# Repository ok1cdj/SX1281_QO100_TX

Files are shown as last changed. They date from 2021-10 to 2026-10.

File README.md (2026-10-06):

# SX1281_QO100_TX
QO-100 SAT CW and Feld Hell Transmitter with OLED Display using 2.4 GHz LoRa module with TCXO by OM2JU and OK1CDJ

https://www.nicerf.com/products/detail/500mw-2-4ghz-lora-wireless-transceiver-module-lora1280f27-lora1281f27.html

Modes: CW and Feld Hell (122.5 Bd, decoded e.g. by fldigi). Feld Hell is sent as a beacon or as any text from the
[pyCWdclient](pyCWdclient/README.md) client or over HTTP - see [Feld Hell](#feld-hell).

*Maximal power output is 450mW. It is enought to work over satellite with 60cm DISH, but tested also with 35cm and helix feed.*

## Features
- Paddle input -IAMBIC keyer
- Straight key input
- Change frequency, power, keyer speed by rotary encoder
- Frequency callibration
- CW beacon mode
- cwdaemon compatible UDP server on port 6789
- WiFi client or AP mode
- Web interface for WiFi config
- Web interafce for tuning, change speed and power
- New: PTT output on ESP32 module pin-12. This is logic signal, one must add external NPN/MOSFET. Configurable delay.
- Wi-Fi keep-alive: modem sleep off, automatic reconnect (fixes drop-outs with mesh APs such as TP-Link Deco)
- Firmware and web files update over Wi-Fi (OTA) - see below
- Feld Hell: beacon set from the web page, text sent from the client or over HTTP - see below
- Python client [pyCWdclient](pyCWdclient/README.md) for desktop and iPad: CW and Feld Hell TX, Feld Hell RX,
  frequency and power control, QSO logging to Wavelog
- Web interface usable on mobile phones

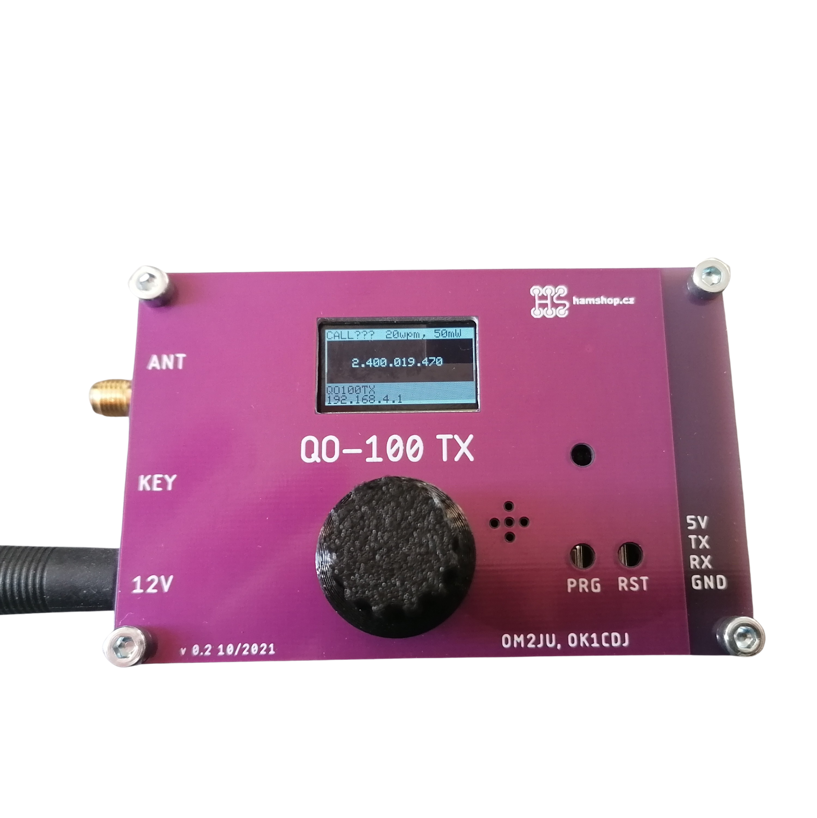
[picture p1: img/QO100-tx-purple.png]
QO-100 TX


## Python client (pyCWdclient)
[`pyCWdclient/`](pyCWdclient/README.md) is a desktop (Tk) and iPad (Pythonista) client for the keyer:
CW macros over UDP (cwdaemon protocol), Feld Hell TX through the web API, Feld Hell receiver
(Linux, audio from an SDR), TX frequency and power control, frequency memories and QSO logging
to Wavelog.

```sh
cd pyCWdclient
cp config.example.json config.json   # keyer IP, call, Wavelog
python3 pyCWdclient.py
```

## Used libraries
Adafruit GFX Library

Adafruit_SSD1306

SX12XX Library - https://github.com/StuartsProjects/SX12XX-LoRa

ESPAsyncWebServer - https://github.com/me-no-dev/ESPAsyncWebServer

AsyncTCP - https://github.com/me-no-dev/AsyncTCP

## Building with PlatformIO
`platformio.ini` builds with Arduino-ESP32 core 2.0.17 (core 3.x is not supported). The web
interface lives in `data/` and goes to the SPIFFS partition.

```sh
pio run -t upload        # firmware over USB
pio run -t uploadfs      # web files over USB
```

## OTA update
Open `http://<keyer IP>/update?apikey=<APIKEY>`, choose *Firmware* (`firmware.bin`) or
*Web files* (`spiffs.bin`) and press Update. The keyer restarts after a successful upload;
settings are kept. With PlatformIO:

```sh
KEYER_APIKEY=1111 pio run -e ota -t upload   --upload-port <keyer IP>
KEYER_APIKEY=1111 pio run -e ota -t uploadfs --upload-port <keyer IP>
```

There is no automatic rollback - a firmware that does not start needs a USB flash
(hold BOOT, press EN).

## Feld Hell
Standard Feld Hell (7x14 font, 245 pixels/s, 2.5 characters/s, on/off keying), decoded by the
Feld Hell mode of fldigi. Text, number of repetitions (0 = until Stop) and pause between them
are set on the web page and kept after restart; `%CALL%` in the text is replaced by MyCall.
Start/Stop from the web page, from the menu (*Beacon FHELL*) or by HTTP:

```sh
curl "http://<keyer IP>/hell?apikey=<APIKEY>&cmd=start"   # cmd=stop, no cmd = status
```

Any text can be sent once with `cmd=send&txt=<text>`; text sent while the keyer is still
transmitting is appended (up to 512 characters). This is what the pyCWdclient client uses in its
Hell mode (macros and free text); the client also receives Feld Hell from an SDR.

Break (web, UDP) or the encoder push button stops Feld Hell and drops the rest of the text.
CW text is not sent while Feld Hell is being transmitted.

## User interface
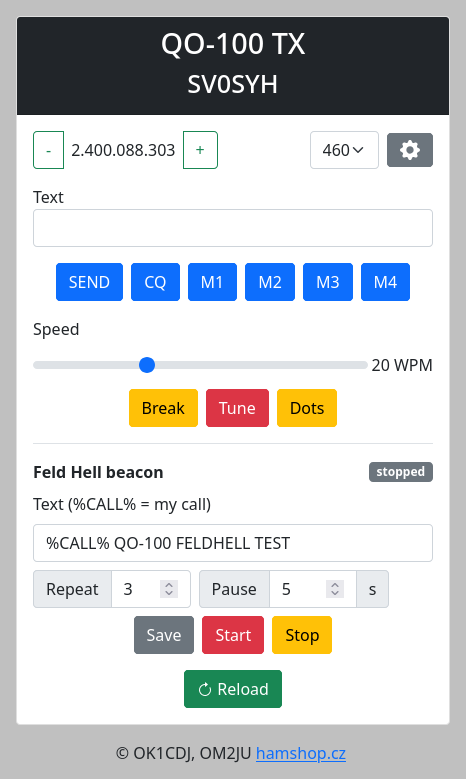
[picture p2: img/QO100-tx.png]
Web interface


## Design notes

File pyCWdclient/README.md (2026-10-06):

# pyCWdclient

Tk GUI client for [cwdaemon](https://github.com/acerion/cwdaemon) compatible keyers (e.g. an ESP32 keyer)
for CW and Feld Hell operation via QO-100. Sends CW macros over UDP and logs QSOs to [Wavelog](https://github.com/wavelog/wavelog) as ADIF.

Part of [SX1281_QO100_TX](https://github.com/ok1cdj/SX1281_QO100_TX) - the client for its keyer
(CW and Feld Hell TX, Feld Hell RX, frequency and power control).

## Setup

```sh
pip install -r requirements.txt
cp config.example.json config.json   # edit IP, station, macros, Wavelog
python pyCWdclient.py
```

QSOs are uploaded to [Wavelog](https://github.com/wavelog/wavelog) (`wavelog` in the config: URL,
API key with write rights, station profile ID). Cloudlog works too; an old `cloudlog` config key
is still read.

Wavelog credentials can also be given on the command line (they override the config):

```sh
python pyCWdclient.py <url> <api_key> <station_id>
```

## Macros

Placeholders: `{mycall}`, `{name}`, `{myloc}` (from `station`), `{call}`, `{rst}` (from the GUI).

## Keys

| Key | Action |
|-----|---|
| F1 | CQ |
| F2 | Report (`rpt` macro) |
| F3 | TU 73 |
| F4 | de .. |
| F5 / Enter | Send free text |
| Esc | Stop transmission (CW abort + keyer Break) |
| F6 | Dots (keyer) |
| PgUp / PgDn | Tune up / down by the selected step |

## Pythonista (iPad / iPhone)

`pyCWdclient_ios.py` is the same client with a touch UI for [Pythonista 3](http://omz-software.com/pythonista/).
The logic (cwdaemon, keyer, tuning, memories, ADIF, Wavelog) is shared in `cwcore.py`;
`pyCWdclient.py` is the Tk frontend.

1. Copy `cwcore.py`, `pyCWdclient_ios.py` and your `config.json` into one Pythonista folder
   (e.g. via iCloud Drive / the Files app). No extra packages are needed.
2. Run `pyCWdclient_ios.py`. Allow *Local Network* access for Pythonista when iOS asks
   (Settings → Pythonista → Local Network), otherwise UDP and the keyer are unreachable.
3. Memories are stored in `memories.json` next to the config, separately from the desktop.

Memories: *Save* stores the current frequency, *Memories* lists them — tap to tune, swipe left
to delete. With a hardware keyboard: Esc = STOP, ⌘1–⌘4 = CQ / Report / TU 73 / de ..,
⌘D = Dots, ⌘↑ / ⌘↓ = tune, ⌘L = Log QSO.

`../UDP_Test_script.py` is a standalone UDP test script (sends a test message at 15 and 30 WPM).

## Frequency

If `keyer_web.url` is set, the TX frequency is read from the QO-100 TX keyer web page
(`frq_index × STEP`, polled every `poll_s` seconds), shown in the app and logged with each QSO.
`FREQ_RX` is TX + `adif.rx_offset_mhz` (8089.5 MHz for the QO-100 NB transponder).
If the keyer is unreachable, `adif.freq` is logged.

Tuning: `−`/`+` buttons, mouse wheel over the frequency or PgUp/PgDn, with a selectable step
(one keyer step ≈ 198 Hz, 1/10/100 kHz; kHz steps snap to the grid). Type a frequency in MHz
and press GO/Enter to jump to it. Memories are saved to `memories.json` next to the config.

`keyer_web.correction_hz` corrects the TCXO offset: set it to
*real frequency (SDR/GPS) − frequency shown with correction 0*.

## Dots and power

`DOTS` (F6) makes the keyer send a series of dots (25× E) for tuning onto the transponder.
STOP / Esc aborts CW and sends Break, which clears the keyer's CW queue.
Power is selected from the levels offered by the keyer and follows changes made in its web UI.

## Feld Hell

The CW / Hell switch (F7, ⌘H on the iPad) sends macros and free text in Feld Hell instead of
CW. Hell text goes to the keyer over its web API (`/hell?cmd=send`, needs `keyer_web` and
keyer firmware v1.7+); messages sent while the keyer is still transmitting are appended.
STOP sends Break, which also stops Hell. QSOs logged in Hell mode get `MODE=HELL`.

### Receiving (Tk on Linux)

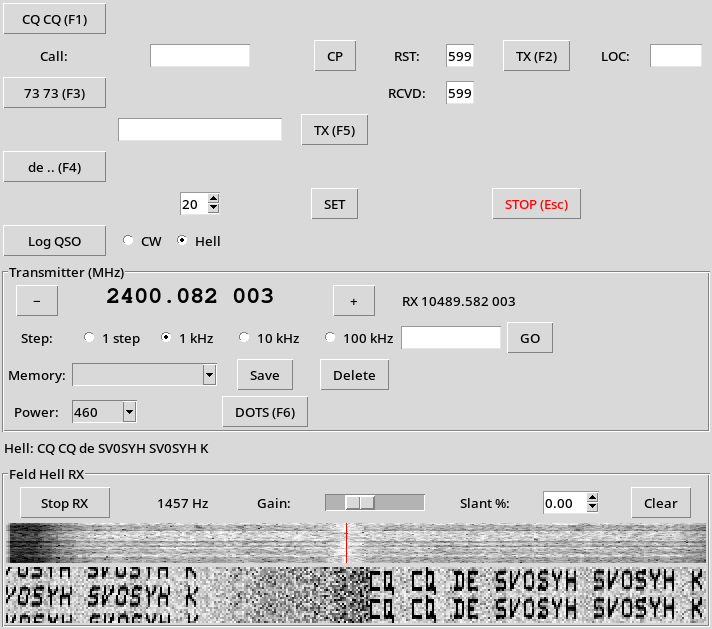
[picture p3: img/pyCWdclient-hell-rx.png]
pyCWdclient receiving Feld Hell


The *Feld Hell RX* panel decodes Feld Hell from audio, e.g. a WebSDR playing in the
browser. It needs `numpy` and `parec` (PulseAudio / PipeWire); without them the panel is
hidden. Audio is taken from `hell_rx.source`, by default `@DEFAULT_MONITOR@` = whatever plays
in the default output. A different source can be chosen in `pavucontrol` → Recording.

Start RX, click the signal in the waterfall (0–3 kHz) to set the tone, adjust Gain for
contrast and Slant % if the text leans. Each column is drawn twice on top of each other, as in
fldigi, so a full character is always readable in one of the copies.

`python3 hellrx.py ../Settings.h out.pgm "TEXT"` decodes a generated
test signal offline (font read from the keyer firmware).

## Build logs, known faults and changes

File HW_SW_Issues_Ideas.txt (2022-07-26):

--------------------------------------------------------
JU - comments to initial PCB revision from 24.08.2021:
  
  - move LD117ADT more to left or right so that we can put there distance pole for OLED display (right hole is OK, left one intersects with LD117ADT)
    Note: with max. output power the current drawn is very high and will not work with standard USB port. Solution is to set lower output power.
--------------------------------------------------------
JU 2022-07-26: 
I have soldered micro-USB receptacle so that the SX1281_QO100_TX can be supplied by USB power bank.
From micro-USB receptacle simply connect:
- the 5V pin  (pin-1 = VBUS) to 5V rail on SX1281_QO100_TX
- the GND pin (pin-5 = GND) to GND on SX1281_QO100_TX
--------------------------------------------------------

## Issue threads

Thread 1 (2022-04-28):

Wrong Buzzer initialisation ...

F5MDY, 2022-04-28:
Good job !!

In the setup () wrong Buzzer Channel initialization

Original :

 // Configure BUZZER functionalities.
  ledcSetup(3, 8000, 8);   //PWM Channel, Freq, Resolution
  /// Attach BUZZER pin.
  ledcAttachPin(BUZZER, 3);  // Pin, Channel

should become :

 // Configure BUZZER functionalities.
  ledcSetup(9, 8000, 8);   //PWM Channel, Freq, Resolution
  /// Attach BUZZER pin.
  ledcAttachPin(BUZZER, 9);  // Pin, Channel

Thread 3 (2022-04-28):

No power output modification

F5MDY, 2022-04-28:
I use a E282G4M27S from Ebyte (without TCXO ... it's a pitty) and the output power is always the same (22dBm) regardless the output power selection.
73

renef6bir, 2022-05-24:
Bonjour avez vous finalisé le projet, j'en suis à la réalisation d'une maquette et il me manque quelques infos
Jutilise un NodeMcu-esp32s et un  LoRa1281f27 sans TCXO
73 René F6bir

renef6bir, 2022-06-07:
Je bloque sur la ligne 1322
**_if (LT.begin(NSS, NRESET, RFBUSY, DIO1, DIO2, DIO3, RX_EN, TX_EN, SW, LORA_DEVICE))_**
Pas de réponse du module ? le serial print monitor  indique la date la version et "SPI OK"
Le display Oled se termine par "Starting WiFi..."
L'essai du module LoRa avec un Arduino nano et plusieurs exemples de la Lib est concluant je vois l'émission 2.4G en DSB avec ou sans l'ampli inboard ( TXEN ou non)

Je souhaitais procéder par étapes et je n'ai pas encore câblé l'encodeur....
Je ne me suis  pas encore soucié du WiFi....
J'ai testé toutes variations du Settings.h qui concerne le module LoRa1281, j'ai vérifié plusieurs fois le câblage.
J'ai tenu compte des différences de pinout entre l'ESP-WROOM-32 et le NodeMCU-esp32s que j'utilise, mais est ce bien compatible ? (voir pdf joint)
La LED1 (IO2) (IO15 dans le settings) ne réagit pas dans aucun des " **_examples_** " de test avec Arduino Nano ou Uno.

Pour info , par ailleurs, j'ai une balise WSPR , à base de raspi, opérationnelle H24 sur QO100 freq  10489.569500 MHz : fréquence du signal, pwr (+17dBm) parabole offset de 60cm hélice 5tr,  upconverter DXPatrol seul, les OL sont GPS locked,  reçu -17dBm sur les WebSDR QO100
Pour la puissance de sortie du LoRa l'alimenter en 3.3v au lieu de 5v (si ce n'est déja fait ) TXEN ne mettrait en service que le PA du module, si j'ai bien cerné le produit.
Auriez vous le schéma de votre réalisation, je n'ai que celui disponible sur GitHub.
Merci pour le retour  73 René f6bir@sfr.fr

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

F5MDY, 2022-06-08:
I found my error ..... I use a SX1280 module (E28-2G4M27S) which have a 27dB PA.
If you check the SX128XLT library, the function setTxParams(int8_t TXpower, uint8_t RampTime) add 18 to the TXpower value (which is given in dBm for SX1280 standalone). So the PowerArrayMiliWatt table values in the program are to high for my module, and its saturate. This is the new correct table for this module :

#define PowerArrayMiliWatt_Size 7
//
// { Power_mW, Reg-setting }
const uint32_t PowerArrayMiliWatt [][2] = {
  {  0,  0 },   // 0mW = no output power, special case
  { 15,  -13 },   // cca 15 mW
  { 25,  -10 },   // cca 25 mW
  { 50, -7 },   // cca 50 mW
  { 100, -4},   // cca 100 mW
  { 150, -2 },  // cca 150 mW
  { 220, 1 }   // cca 220 mW
};

Best 73, Nico

F5MDY, 2022-06-08:
TO René :

J'ai vraiment le minimum pour la connection au module :

#define NSS 5                                  //select pin on LoRa device
#define SCK 18                                  //SCK on SPI3
#define MISO 19                                 //MISO on SPI3
#define MOSI 23                                 //MOSI on SPI3

#define NRESET 32                               //reset pin on LoRa device
#define RFBUSY 33                               //busy line

#define LED1 -1                                 //on board LED, high for on
#define DIO1 26                                 //DIO1 pin on LoRa device, used for RX and TX done
#define DIO2 -1                                 //DIO2 pin on LoRa device, normally not used so set to -1
#define DIO3 -1                                 //DIO3 pin on LoRa device, normally not used so set to -1
#define RX_EN -1                                //pin for RX enable, used on some SX128X devices, set to -1 if not used
#define TX_EN -1                                 //pin for TX enable, used on some SX128X devices, set to -1 if not used
#define BUZZER 12                               //pin for buzzer, set to -1 if not used
#define VCCPOWER -1    //JU-not needed by module          //pin controls power to external devices
#define LORA_DEVICE DEVICE_SX1281               //we need to define the device we are using
#define TCXO_EN -1

J'ai été un peu feignant pour l'implantation : j'ai utilisé des PCB que j'avais d'un autre projet :
https://github.com/thingsat/tinygs_2g4station#buy en apportant quelques modifs.
Mais pour le module 2.4G il est connecté comme décrit

Attention je n'ai pas de SW sur ma ligne 1322 :
  if (LT.begin(NSS, NRESET, RFBUSY, DIO1, DIO2, DIO3, RX_EN, TX_EN, LORA_DEVICE))  {

J'irai écouter votre balise merci de l'info.

73
Nico

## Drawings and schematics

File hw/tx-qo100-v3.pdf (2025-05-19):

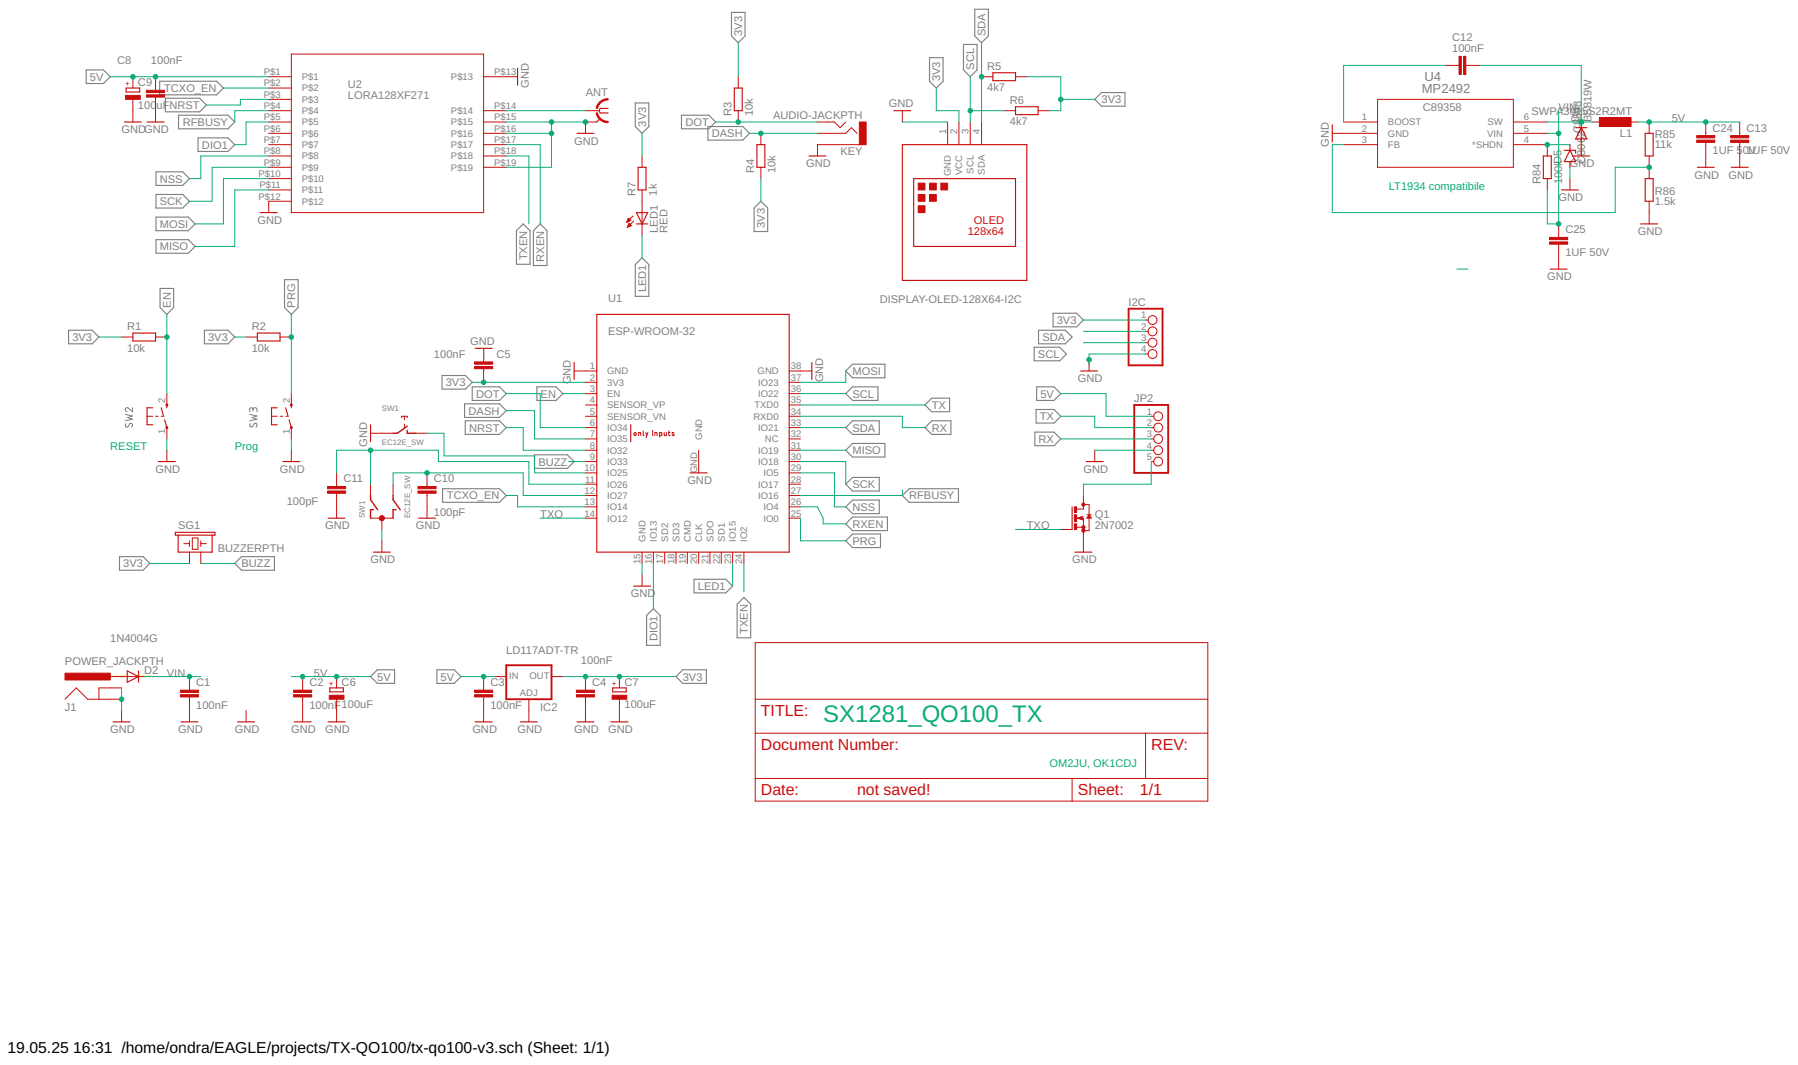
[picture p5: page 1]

Document Number: OM2JU, OK1CDJ | REV:

Date: not saved! | Sheet: 1/1

19.05.25 16:31 /home/ondra/EAGLE/projects/TX-QO100/tx-qo100-v3.sch (Sheet: 1/1)

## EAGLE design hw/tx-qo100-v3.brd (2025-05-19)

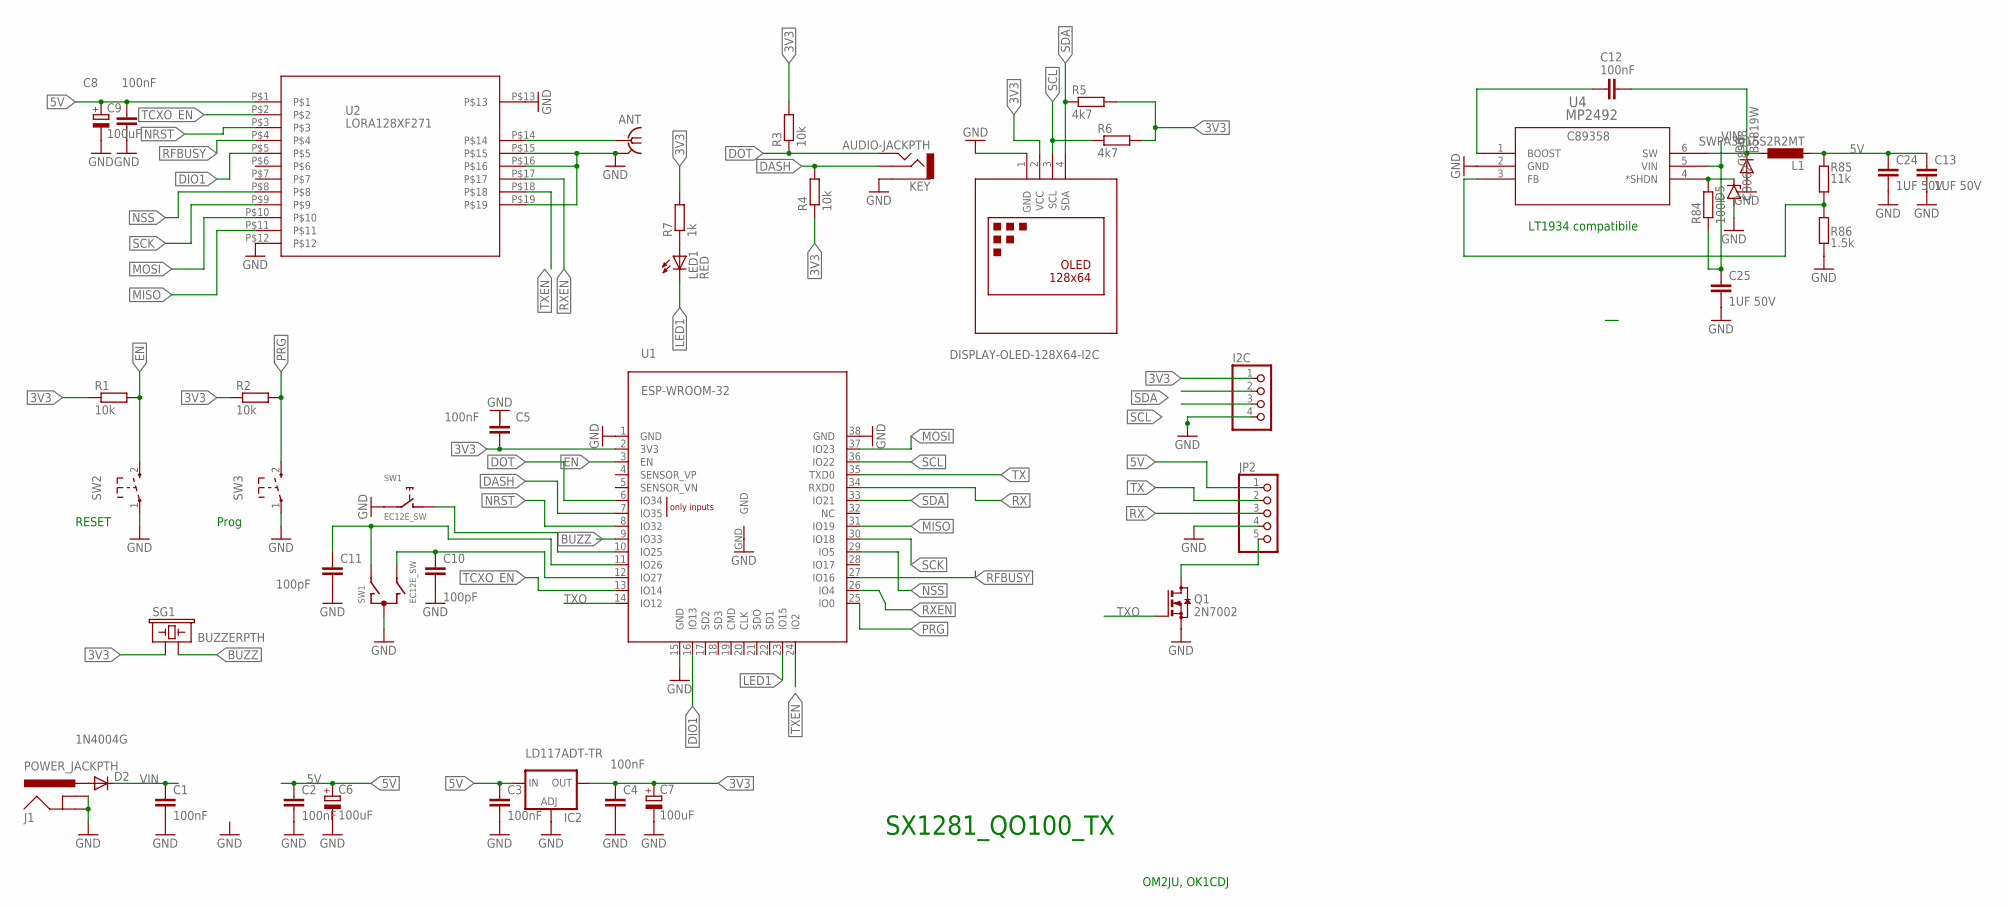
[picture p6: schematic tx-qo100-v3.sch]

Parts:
ANT: SMA-142-0711-821/826; J502-ND-142-0711-821/826
C1, C2, C3, C4, C5, C8, C12: 100nF; C0603
C6, C7, C9: 100uF; SMC_B; LCSC_PART C16133
C10, C11: 100pF; C0603
C13, C24, C25: 1UF 50V; C0603; LCSC_PART C15849
D2: 1N4004G; DO-214AC; LCSC_PART C433394
D5: C8062; SOD80C; LCSC_PART C8062
D6: B5819W; SOD123; LCSC_PART C8598
I2C: PINHD-1X4; 1X04
IC2: LD117ADT-TR; DPACK; LCSC_PART C358375
J1: POWER_JACKPTH; POWER_JACK_PTH
JP2: PINHD-1X5/90; 1X05/90
KEY: AUDIO-JACKPTH; AUDIO-JACK
L1: SWPA3015S2R2MT; L2825P; LCSC_PART C43389
LED1: RED; CHIP-LED0805; LCSC_PART C84256
Q1: 2N7002; SOT23; LCSC_PART C8545
R1, R2, R3, R4: 10k; R0603
R5, R6: 4k7; R0603
R7: 1k; R0603
R84: 100k; R0603
R85: 11k; R0603
R86: 1.5k; R0603
SG1: BUZZERPTH; BUZZER-12MM; LCSC_PART C360607
SW1: EC12E_SW; ALPS_EC12E_SW
SW2, SW3: SW_TACT_2P-3X6; SW_TACT_3X6; LCSC_PART C520860
U1: ESP-WROOM-32
U2: LORA128XF271; LORA128XF27
U4: MP2492; SOT-6_S; LCSC_PART C89358
U$1: DISPLAY-OLED-128X64-I2C

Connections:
3V3: C4.1, C5.1, C7.+, I2C.1, IC2.4 (OUT), R1.1, R2.1, R3.2, R4.1, R5.2, R6.2, R7.2, SG1.+ (1), U1.2 (3V3), U$1.2 (VCC)
5V: C2.1, C3.1, C6.+, C8.1, C9.+, C13.1, C24.1, IC2.3 (IN), JP2.1, L1.2, R85.1, U2.P$1
BST: C12.2, U4.1 (BOOST)
BUZZ: SG1.- (2), U1.9 (IO33)
DASH: KEY.2, R4.2, U1.7 (IO35)
DIO1: U1.16 (IO13), U2.P$5
DOT: KEY.5, R3.1, U1.6 (IO34)
EN: R1.2, SW2.2 (3), U1.3 (EN)
GND: ANT.G@1 (2), ANT.G@2 (2), ANT.G@3 (2), ANT.G@4 (2), C1.2, C2.2, C3.2, C4.2, C5.2, C6.-, C7.-, C8.2, C9.-, C10.2, C11.2, C13.2, C24.2, C25.2, D5.A, D6.A, I2C.4, IC2.1 (ADJ), J1.GND, J1.GNDBREAK, JP2.4, KEY.1, Q1.2 (S), R86.1, SW1.C, SW1.E (2), SW2.1, SW3.1, U1.1 (GND), U1.15 (GND), U1.38 (GND), U1.GND, U2.P$12, U2.P$13, U2.P$15, U2.P$16, U2.P$19, U4.2 (GND), U$1.1 (GND)
IN: D2.A, J1.PWR
LED1: LED1.C, U1.23 (IO15)
MISO: U1.31 (IO19), U2.P$11
MOSI: U1.37 (IO23), U2.P$10
unnamed: ANT.1, U2.P$14
unnamed: C10.1, SW1.B, U1.12 (IO27)
unnamed: LED1.A, R7.1
unnamed: C11.1, SW1.A, U1.11 (IO26)
unnamed: SW1.D (1), U1.10 (IO25)
unnamed: JP2.5, Q1.3 (D)
unnamed: D5.C, R84.2, U4.4 (*SHDN)
unnamed: R85.2, R86.2, U4.3 (FB)
NRST: U1.8 (IO32), U2.P$3
NSS: U1.29 (IO5), U2.P$8
PRG: R2.2, SW3.2 (3), U1.25 (IO0)
RFBUSY: U1.27 (IO16), U2.P$4
RX: JP2.3, U1.34 (RXD0)
RXEN: U1.26 (IO4), U2.P$17
SCK: U1.30 (IO18), U2.P$9
SCL: I2C.3, R6.1, U1.36 (IO22), U$1.3 (SCL)
SDA: I2C.2, R5.1, U1.33 (IO21), U$1.4 (SDA)
SW: C12.1, D6.C, L1.1, U4.6 (SW)
TCXO_EN: U1.13 (IO14), U2.P$2
TX: JP2.2, U1.35 (TXD0)
TXEN: U1.24 (IO2), U2.P$18
TXO: Q1.1 (G), U1.14 (IO12)
VIN: C1.1, C25.1, D2.C, R84.1, U4.5 (VIN)

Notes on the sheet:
RESET
Prog
SX1281_QO100_TX
OM2JU, OK1CDJ
LT1934 compatibile

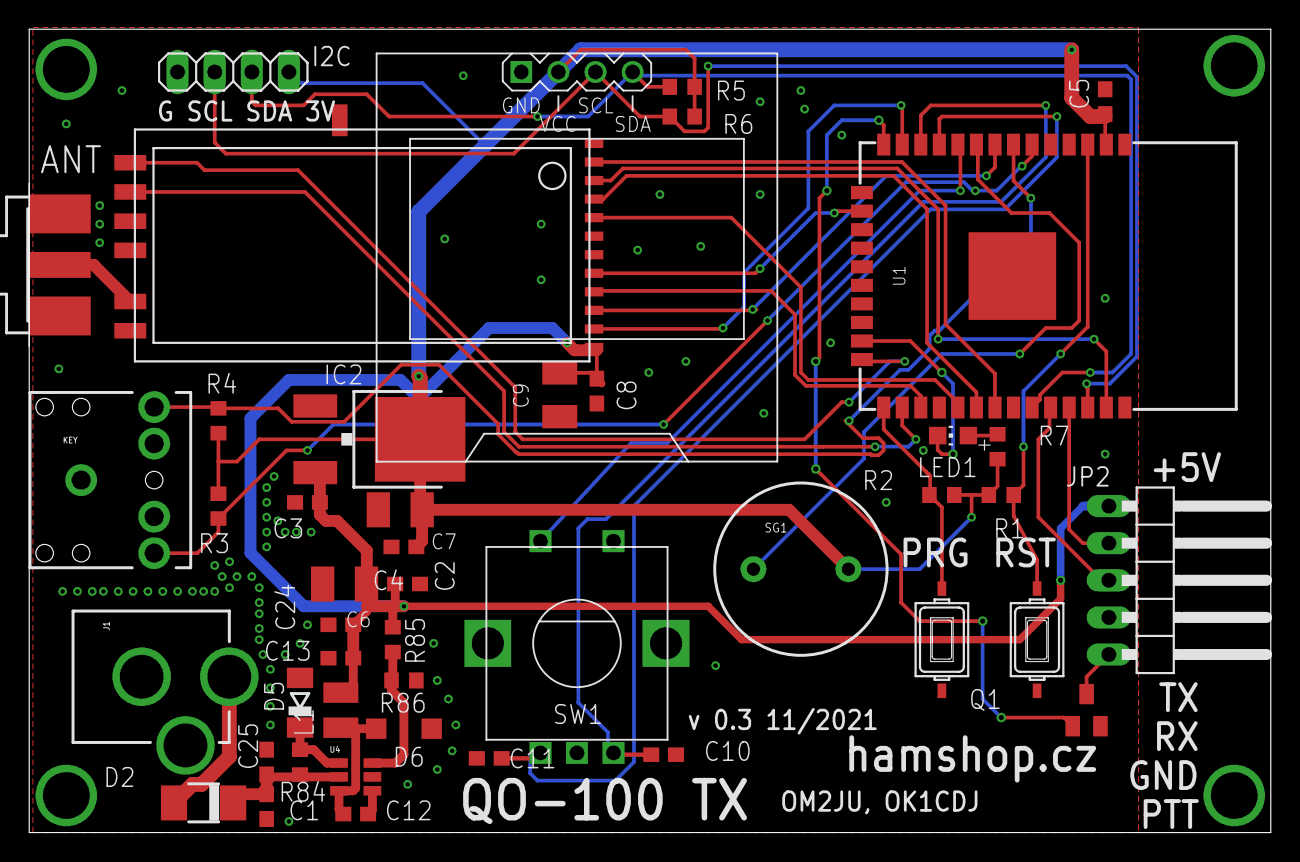
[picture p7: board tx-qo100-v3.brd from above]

Board: 2 copper layers, 85.0 x 55.0 mm, 45 parts (0 on the bottom side), 36 nets.

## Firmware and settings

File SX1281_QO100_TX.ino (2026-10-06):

//
// 2021-08  QO-100 SAT CW Transmitter with OLED Display
// by Jan Uhrin, OM2JU and Ondrej Kolonicny, OK1CDJ
//
//
//
// Power level settings - from documentation of LoRa128xF27 module
// LEV dBm  mA    Reg value
// 9  26.4  520   13
// 8  25.5  426   10
// 7  23.4  343   7
// 6  20.85 268   4
// 5  18.26 229   1
// 4  15.2  182   -2
// 3  12.3  155   -5
// 2  9.3   138   -8
// 1  6.0   130   -12
// 0  3.0   125   -15
//
// SX128x datasheet:  Pout (dB) = -18 + Reg_Value
//
//

#include <Adafruit_GFX.h>
#include <Adafruit_SSD1306.h>
#include <Preferences.h>

#include <WiFi.h>
#include <ESPAsyncWebServer.h>
#include <AsyncUDP.h>
#include <SPIFFS.h>
#include <Update.h>


#include "time.h"
#include <SPI.h>                                               //the lora device is SPI based so load the SPI library                                         
#include <SX128XLT.h>                                          //include the appropriate library  
#include "Settings.h"                                          //include the setiings file, frequencies, LoRa settings etc   


#define UDP_PORT 6789 // UDP port for CW 

#define SCREEN_WIDTH 128 // OLED display width, in pixels
#define SCREEN_HEIGHT 64 // OLED display height, in pixels

// Declaration for an SSD1306 display connected to I2C (SDA, SCL pins)
#define OLED_RESET     -1 // Reset pin # (or -1 if sharing Arduino reset pin)
Adafruit_SSD1306 display(SCREEN_WIDTH, SCREEN_HEIGHT, &Wire, OLED_RESET);

#define PUSH_BTN_PRESSED 0
#define ReadPushBtnVal()   pushBtnVal=digitalRead(ROTARY_ENC_PUSH)
#define WAIT_Push_Btn_Release(milisec)  delay(milisec);while(digitalRead(ROTARY_ENC_PUSH)==0){}

#define TIMER_PERIOD_USEC 2500     // 2500 = 2.5 msec, 3500 = 3.5 msec


// Webserver
AsyncWebServer server(80);
AsyncUDP udp;
QueueHandle_t queue;

String ssid       = "";
String ssid_ap    = "QO100TX";
String password   = "";
String apikey     = "";
String sIP        = "";
String sGateway   = "";
String sSubnet    = "";
String sPrimaryDNS = "";
String sSecondaryDNS = "";
String wifiNetworkList = "";
String spwr = "";

String message;
String sspeed = "20";
String sfreq;
String scmd;
uint32_t speed = 20;

// web server requests
const char* PARAM_MESSAGE = "message";
const char* PARAM_FRQ_INDEX = "frq_index";
const char* PARAM_SPEED = "speed";
const char* PARAM_PWR = "pwr";
const char* PARAM_SSID = "ssid";
const char* PARAM_PASSWORD = "password";
const char* PARAM_APIKEY = "apikey";
const char* PARAM_DHCP = "dhcp";
const char* PARAM_CON = "con";
const char* PARAM_SUBNET = "subnet";
const char* PARAM_GATEWAY = "gateway";
const char* PARAM_PDNS = "pdns";
const char* PARAM_SDNS = "sdns";
const char* PARAM_LOCALIP = "localip";
const char* PARAM_CMD_B   = "cmd_B";
const char* PARAM_CMD_C   = "cmd_C";
const char* PARAM_CMD_D   = "cmd_D";
const char* PARAM_CMD_T   = "cmd_T";
const char* PARAM_CMD_M1  = "cmd_M1";
const char* PARAM_CMD_M2  = "cmd_M2";
const char* PARAM_CMD_M3  = "cmd_M3";
const char* PARAM_CMD_M4  = "cmd_M4";
const char* PARAM_VAL     = "val";
const char* PARAM_HELL_TXT    = "hell_txt";
const char* PARAM_HELL_REP    = "hell_rep";
const char* PARAM_HELL_PAUSE  = "hell_pause";
const char* PARAM_CMD_HELL    = "cmd_H";
const char* PARAM_CMD_HELL_X  = "cmd_HX";
const char* PARAM_CMD         = "cmd";
const char* PARAM_TXT         = "txt";


bool wifiConfigRequired = false;
bool wifiSoftAP = false;
bool dhcp = true; // dhcp enable disble
bool con = false; // connection type wifi false

IPAddress IP;
IPAddress gateway;
IPAddress subnet;
IPAddress primaryDNS;
IPAddress secondaryDNS;


// Program state
enum state_t {
  S_RUN = 0,
  S_RUN_RUN,
  S_TOP_MENU_ITEMS,
  S_RUN_CQ,
  S_SET_SPEED_WPM,
  S_SET_OUTPUT_POWER,
  S_SET_KEYER_TYPE,
  S_SET_FREQ_OFFSET,
  S_SET_BUZZER_FREQ,
  S_SET_PTT_TIMEOUT,
  S_SET_TEXT_GENERIC,
  S_SET_ROTARY_ENC_DIRECTION,
  S_WIFI_RECONNECT,
  S_RUN_BEACON,
  S_RUN_BEACON_HELL
} program_state;

// States when text value is modified
enum set_text_state_t {
  S_SET_MY_CALL = 0,
  S_SET_WIFI_SSID,
  S_SET_WIFI_PWD,
  S_SET_M1_TEXT,          // Memory 1
  S_SET_M2_TEXT,          // Memory 2
  S_SET_M3_TEXT,          // Memory 3
  S_SET_M4_TEXT           // Memory 4
} set_text_state;


// Perl script to dump out power reg. setting, dBm value, and mWatt value
// for($i=-1;$i<13;$i++) { print $i+1 . " "; print 18.26+0.7*$i . " " . 10**((18.26+0.7*$i)/10). "\n"; }
// 0 17.56 57.0164272280748
// 1 18.26 66.9884609416526
// 2 18.96 78.7045789695099
// 3 19.66 92.4698173938223
// 4 20.36 108.642562361707
// 5 21.06 127.643880881134
// 6 21.76 149.968483550237
// 7 22.46 176.197604641163
// 8 23.16 207.014134879104
// 9 23.86 243.220400907382
// 10 24.56 285.759054337495
// 11 25.26 335.737614242955
// 12 25.96 394.457302075279
// 13 26.66 463.446919736288
//
//
#define PowerArrayMiliWatt_Size 6
// { Power_mW, Reg-setting }
const uint32_t PowerArrayMiliWatt [][2] = {
  {  0,  0 },   // 0mW = no output power, special case
  { 50,  0 },   // cca 50 mW
  { 100, 4 },   // cca 100 mW
  { 200, 8 },   // cca 200 mW
  { 330, 11 },  // cca 300 mW
  { 460, 13 }   // cca 460 mW       13+18 = 31  --> max value
};
//
// Menu definition
const char * TopMenuArray[] = {
  "1. < Back / ",           // shorter as we display version afterwards    
  "2. CQ...          ",
  "3. Set WPM        ",
  "4. Set Out Power  ",
  "5. Set Keyer Typ  ",
  "6. Set Offset Hz  ",
  "7. Set Buzzer Freq",
  "8. Set PTT timeout",
  "9. Set My Call    ",
  "10. Set Play Mem_1",
  "11. Set Play Mem_2",
  "12. Set Play Mem_3",
  "13. Set Play Mem_4",
  "14. Set WiFi SSID ",
  "15. Set WiFi PWD  ",
  "16. WiFi Reconnect",
  "17. Set EncoderDir",
  "18. Beacon (vvv)  ",
  "19. Beacon FHELL  "
};
//
// Rotary Encoder structure
struct RotaryEncounters
{
  int32_t cntVal;      // actual value
  int32_t cntMin;      // minimum
  int32_t cntMax;      // maximum
  int32_t cntIncr;     // increment
  int32_t cntValOld;   // for detection if value has changed
};

hw_timer_t * timer = NULL;
//TFT_eSPI     tft   = TFT_eSPI();  // Invoke library, pins defined in User_Setup.h
SX128XLT LT;                      // Create a library class instance called LT

#define DOT  0
#define DASH 1
uint8_t  rotaryA_Val = 0xFF;
uint8_t  rotaryB_Val = 0xFF;
uint8_t  RotaryEnc_Pin_A = ROTARY_ENC_A;
uint8_t  RotaryEnc_Pin_B = ROTARY_ENC_B;
uint8_t  ISR_cnt = 0;
uint8_t  cntIncrISR;
uint32_t loopCnt = 0;
uint32_t menuIndex;
uint32_t timeout_cnt = 0;
uint8_t  keyerVal      = 1;
uint8_t  lastPlayedPad = DOT;
uint8_t  iambicBfinishFlag;
uint8_t  pushBtnVal    = 1;
uint8_t  keyerCWstarted = 0;
uint8_t  pushBtnPressed = 0;
uint8_t  stop = 0;
uint32_t  tmp32a, tmp32b;

uint32_t FreqWord = 0;
uint32_t FreqWordNoOffset = 0;
uint32_t WPM_dot_delay;
uint32_t WPM_dash_delay;
uint32_t PttTimeoutCnt = 0; 
uint32_t PttTimeoutCntStartValue;


char   freq_ascii_buf[20];   // Buffer for formatting of FREQ value
char   general_ascii_buf[128];
uint8_t general_ascii_buf_index = 0;
char   mycall_ascii_buf[64];
char   wifi_ssid_ascii_buf[64];
char   wifi_pwd_ascii_buf[64];
bool   params_set_by_udp_packet = false;
char   morse_c, morse_c_old;
String   s_M1_ascii_buf;     // Memory-1
String   s_M2_ascii_buf;     // Memory-2
String   s_M3_ascii_buf;     // Memory-3
String   s_M4_ascii_buf;     // Memory-4

String s_mycall_ascii_buf;
//String s_wifi_ssid_ascii_buf;
//String s_wifi_pwd_ascii_buf;
String s_general_ascii_buf;
String udpdataString;

char   cq_message_buf[] =     "CQ CQ DE ";
char   cq_message_end_buf[] = " +K";
char   beacon_message_buf[] = "VVV  VVV  VVV  TEST  ";
char   eee_message_buf[] =    "E E E E E E E E E E E E E E E E E E E E E E E E E";

// Feld Hell beacon - text and repetition are stored in preferences, %CALL% is replaced by MyCall
#define HELL_TEXT_MAX   64
#define HELL_PIXEL_US   4082          // 1e6 / 245 - Feld Hell half-pixel (122.5 Bd)
String s_hell_text;
int    hell_repeat;                   // 0 = until stopped
int    hell_pause;                    // seconds between repetitions
volatile bool hellActive  = false;
volatile bool hellStopReq = false;
volatile bool morseSending = false;
TaskHandle_t hellTaskHandle = NULL;
// Text sent once from /hell?cmd=send - more text can be appended while it is being sent
#define HELL_QUEUE_MAX  512
String hellQueue;
SemaphoreHandle_t hellMutex;          // guards hellQueue and the start/end of the Hell task
volatile bool hellBeaconMode = false;

RotaryEncounters RotaryEnc_FreqWord;
RotaryEncounters RotaryEnc_MenuSelection;
RotaryEncounters RotaryEnc_KeyerSpeedWPM;
RotaryEncounters RotaryEnc_KeyerType;
RotaryEncounters RotaryEnc_OffsetHz;
RotaryEncounters RotaryEnc_BuzzerFreq;
RotaryEncounters RotaryEnc_PttTimeout;
RotaryEncounters RotaryEnc_OutPowerMiliWatt;
RotaryEncounters RotaryEnc_TextInput_Char_Index;
RotaryEncounters RotaryEncISR;
RotaryEncounters RotaryEnc_RotaryEnc_Dir;

Preferences preferences;

// Copy values of variable pointed by r1 to RotaryEncISR variable
void RotaryEncPush(RotaryEncounters *r1) {
  RotaryEncISR = *r1;
  RotaryEncISR.cntValOld = RotaryEncISR.cntVal + 1;  // Make Old value different from actual in order to e.g. force initial update of display
}

// Copy values of RotaryEncISR variable to variable pointed by r1
void RotaryEncPop(RotaryEncounters *r1) {
  *r1 = RotaryEncISR;
}


// Display - Prepare box and cursor for main field
void display_mainfield_begin(uint8_t x) {
  display.setTextColor(WHITE);
  //display.clearDisplay();
  display.fillRect(1, 10, SCREEN_WIDTH - 2, 35, BLACK); // x, y, width, height
  display.setTextSize(1);
  display.setCursor(x, 25);
}

// Display - Prepare box and cursor for value field
void display_valuefield_begin () {
  display.fillRect(5, 43 - 2, SCREEN_WIDTH - 10, 12, WHITE); // x, y, width, height
  display.fillRect(6, 43 - 2 + 1, SCREEN_WIDTH - 10 - 2, 12 - 2, BLACK); // x, y, width, height
  display.setTextColor(WHITE);
  display.setTextSize(1);
  display.setCursor(20, 43);
  //display.fillRect(10,30,90,50,BLACK);
}

// Display - Clear the valuefield box
void display_valuefield_clear () {
  display.fillRect(5, 43 - 2, SCREEN_WIDTH - 10, 12, BLACK); // x, y, width, height
}

// Display - show values on status bar
void display_status_bar () {
  // Delete old info by drawing rectangle
  display.fillRect(0, SCREEN_HEIGHT - 9 - 9, SCREEN_WIDTH, 9 + 9, WHITE); // x, y, width, height
  display.fillRect(0, 0, SCREEN_WIDTH, 9, WHITE); // x, y, width, height
  //
  display.setTextColor(BLACK);
  display.setTextSize(1);
  //
  // Display MY_CALL, configured WPM (or Straight keyer) and configured power in mW
  display.setCursor(1, 1); // 7 is the font height
  display.print(s_mycall_ascii_buf);
  display.setCursor(52, 1); // 7 is the font height
  if ((RotaryEnc_KeyerType.cntVal) == 1) {
    display.print("Strgh,");
  } else {
    display.print(RotaryEnc_KeyerSpeedWPM.cntVal);
    if ((RotaryEnc_KeyerType.cntVal) == 0) {
      display.print("wpA,");
    } else {
      display.print("wpB,");
    }
  }
  display.print(PowerArrayMiliWatt[RotaryEnc_OutPowerMiliWatt.cntVal][0]);
  display.print("mW");
  // Display WiFi SSID and IP address
  display.setCursor(1, SCREEN_HEIGHT - 8 - 8); // 7 is the font height
  display.print(wifiSoftAP == false ? ssid.c_str() : ssid_ap.c_str());
  display.setCursor(1, SCREEN_HEIGHT - 8); // 7 is the font height
  display.print(IP);
  display.display();
}


// Limit values of RotaryEncISR.cntVal
void limitRotaryEncISR_values() {
  if (RotaryEncISR.cntVal >= RotaryEncISR.cntMax) {
    RotaryEncISR.cntVal = RotaryEncISR.cntMax;
  }
  if (RotaryEncISR.cntVal <= RotaryEncISR.cntMin) {
    RotaryEncISR.cntVal = RotaryEncISR.cntMin;
  }
}

// Calculate duration of DOT from WPM
void Calc_WPM_dot_delay ( uint32_t wpm) {
  WPM_dot_delay  = (uint32_t) (double(1200.0) / (double) wpm);
  WPM_dash_delay = WPM_dot_delay+WPM_dot_delay+WPM_dot_delay;
}

// Calculate duration of DOT from WPM  - make it a bit longer so that UDP keyer plays slower
void Calc_WPM_dot_delay_a_bit_slower ( uint32_t wpm) {
  WPM_dot_delay  = (uint32_t) (double(1200.0) / (double) wpm) + 1;
  WPM_dash_delay = WPM_dot_delay+WPM_dot_delay+WPM_dot_delay;
}

//
// Refer to SX1280/1281 datasheet, state diagram in page 57. - Figure 10-1: Transceiver Circuit Modes
//
// 1. Command SET_TXCONTINUOUSWAVE will get the TRX state machine to TX mode
// 2. Command SET_FS will get the TRX state machine to FS mode (Freq. Synthesis)
//
// We should never go to STDBY mode since we want that PLL always runs
//
// Start CW - from FS to TX mode
void startCW() {
  PttTimeoutCnt = PttTimeoutCntStartValue;
  digitalWrite(PTT_OUT, 1);
  digitalWrite(LED1, LOW);
  ledcWriteTone(3, RotaryEnc_BuzzerFreq.cntVal);
  if (RotaryEnc_OutPowerMiliWatt.cntVal > 0) {
    LT.txEnable();
    LT.writeCommand(RADIO_SET_TXCONTINUOUSWAVE, 0, 0);
  }
}

// Stop CW - from TX to FS mode
void stopCW() {
  digitalWrite(LED1, HIGH);
  ledcWriteTone(3, 0);
  if (RotaryEnc_OutPowerMiliWatt.cntVal > 0) {
    LT.writeCommand(RADIO_SET_FS, 0, 0);  // This will terminate TXCONTINUOUSWAVE
    LT.rxEnable();                        // No real need for this but it saves power
  }
}
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
void loop()
{
  WiFiKeepAlive();
  OtaRestartCheck();
  //-----------------------------------------
  // RotaryEnc_KeyerType.cntVal -->   0 = Iambic-A, 1 = Straight, 2 = Iambic-B
  // -- Straight keyer
  if (RotaryEnc_KeyerType.cntVal & 0x00000001) {
    keyerVal = digitalRead(KEYER_DOT);
    // Keyer pressed
    if (keyerVal == 0)  {
      if (keyerCWstarted == 0) {
        startCW();
      }
      keyerCWstarted = 1;
      delay(10);
    }
    // Keyer released
    if ((keyerVal == 1) && (keyerCWstarted == 1)) {
      keyerCWstarted = 0;
      stopCW();
      delay(10);
    }
  } else {
    // -- Iambic keywer
    keyerVal   = digitalRead(KEYER_DASH) << 1 | digitalRead(KEYER_DOT);
    iambicBfinishFlag=0;
    switch(keyerVal) {
      case 0x02:   // DOT
        startCW();
        //delay(WPM_dot_delay);
        // here we set iambicBfinishFlag to 0 by passing PADS_NOT_SQUEEZED to function
        wpm_delay_and_paddle_check(WPM_dot_delay, 0x02, 0); // delay WPM_dot_delay with checking if paddles released
        stopCW();
        wpm_delay_and_paddle_check(WPM_dot_delay, 0x02, 0);
        lastPlayedPad = DOT;
      break;
      case 0x01:   // DASH
        startCW();
        // here we set iambicBfinishFlag to 0 by passing PADS_NOT_SQUEEZED to function
        wpm_delay_and_paddle_check(WPM_dash_delay, 0x01, 0);
        stopCW();
        wpm_delay_and_paddle_check(WPM_dot_delay, 0x01, 0);  
        lastPlayedPad = DASH;
      break;
      case 0x00:   // SQUEEZED = BOTH Paddles pressed
        startCW();
        if (lastPlayedPad == DOT) {
          iambicBfinishFlag  = wpm_delay_and_paddle_check(WPM_dash_delay, 0x02, 1);
          stopCW();
          iambicBfinishFlag  += wpm_delay_and_paddle_check(WPM_dot_delay, 0x02, 1);
          lastPlayedPad = DASH;
          // here iambicBfinishFlag will have max 4
        } else {
          iambicBfinishFlag = wpm_delay_and_paddle_check(WPM_dot_delay, 0x01, 10);
          stopCW();
          iambicBfinishFlag += wpm_delay_and_paddle_check(WPM_dot_delay, 0x01, 10);
          lastPlayedPad = DOT;
          // here iambicBfinishFlag will have max 20
        }
      break;
      case 0x03:    // No paddle pressed = no action
      break;
      default:
      break;
    }
    //
    // For Iambic-B keyer play finishing dot or dash if keys released 
    if (iambicBfinishFlag > 0) {
      startCW();
      delay(WPM_dot_delay);
      if (iambicBfinishFlag >= 10) {  // play DASH
        delay(WPM_dot_delay);
        delay(WPM_dot_delay);
      }
      stopCW();
      delay(WPM_dot_delay);
      iambicBfinishFlag=0;
    }

  } // end else iambic keyer
  // Process timeout for display items other than main screen
  if (program_state != S_RUN_RUN) {
    if (timeout_cnt > 6000) {
      display_valuefield_clear();
      display_valuefield_begin();
      display.print("Timeout...");
      display.display();
      delay(600);
      timeout_cnt = 0;
      RotaryEncPush(&RotaryEnc_FreqWord);
      program_state = S_RUN;
    }
  }
  //
  // PTT
  if (PttTimeoutCnt != 0) {
    digitalWrite(PTT_OUT, 1);
    // Debug info on display - but has performance penalty...
    //if (PttTimeoutCnt == PttTimeoutCntStartValue) {
    //  PttTimeoutFirstLoop = 0;
    //  display.setTextColor(BLACK);
    //  display.setTextSize(1);
    //  display.setCursor(SCREEN_WIDTH-12, SCREEN_HEIGHT - 8); // 7 is the font height
    //  display.print('|');
    //  display.display();
    //}
    PttTimeoutCnt--;
  } else {
    digitalWrite(PTT_OUT, 0);
    // Debug info on display - but has performance penalty...
    //display.setTextColor(WHITE);
    //display.setTextSize(1);
    //display.setCursor(SCREEN_WIDTH-12, SCREEN_HEIGHT - 8); // 7 is the font height
    //display.print('|');
    //display.display();
  }
  //
  // Main FSM
  //-----------------------------------------
  switch (program_state) {
    //--------------------------------
    case S_RUN:
      timeout_cnt = 0;
      display_valuefield_clear();
      program_state = S_RUN_RUN;
      break;
    //--------------------------------
    case S_RUN_RUN:
      timeout_cnt = 0;
      // Update display with Frequency info when it has changed
      if (RotaryEncISR.cntVal != RotaryEncISR.cntValOld) {
        limitRotaryEncISR_values();
        display_mainfield_begin(23);
        format_freq(RegWordToFreq(RotaryEncISR.cntVal), freq_ascii_buf, params_set_by_udp_packet);
        params_set_by_udp_packet = false;
        display.print(freq_ascii_buf);
        display.display();
        JUsetRfFrequency(RegWordToFreq(RotaryEncISR.cntVal), RotaryEnc_OffsetHz.cntVal);
        display_status_bar();
      }
      RotaryEncISR.cntValOld = RotaryEncISR.cntVal;
      // This has to be at very end since with RotaryEncPush we are making RotaryEncISR.cntValOld different from RotaryEncISR.cntVal
      ReadPushBtnVal();
      if (pushBtnVal == PUSH_BTN_PRESSED && hellActive) {
        hellStop();
        WAIT_Push_Btn_Release(200);
      } else if (pushBtnVal == PUSH_BTN_PRESSED) {
        WAIT_Push_Btn_Release(200);
        program_state = S_TOP_MENU_ITEMS;
        RotaryEncPop(&RotaryEnc_FreqWord);
        RotaryEncPush(&RotaryEnc_MenuSelection);
      }
      break;
    //--------------------------------
    case S_TOP_MENU_ITEMS:
      // Wrap aroud
      menuIndex = RotaryEncISR.cntVal % (sizeof(TopMenuArray) / sizeof(TopMenuArray[0]));
      // Update display if there is change
      if (RotaryEncISR.cntVal != RotaryEncISR.cntValOld) {
        timeout_cnt = 0;
        display_mainfield_begin(10);
        display.print(TopMenuArray[menuIndex]);
        if (menuIndex==0) {
          display.print(Program_Version);
        }
        display.display();
      }
      RotaryEncISR.cntValOld = RotaryEncISR.cntVal;
      // Decide into which menu item to go based on selection
      ReadPushBtnVal();
      if (pushBtnVal == PUSH_BTN_PRESSED) {
        WAIT_Push_Btn_Release(200);
        RotaryEncPop(&RotaryEnc_MenuSelection);
        switch (menuIndex) {
          // -----------------------------
          case 0:
            program_state = S_RUN;
            RotaryEncPush(&RotaryEnc_FreqWord); // makes RotaryEncISR.cntValOld different from RotaryEncISR.cntVal  ==> forces display update
            break;
          // -----------------------------
          case 1:
            program_state = S_RUN_CQ;
            display_valuefield_begin();
            display.print("CQ...");
            display.display();
            break;
          // -----------------------------
          case 2:
            program_state = S_SET_SPEED_WPM;
            RotaryEncPush(&RotaryEnc_KeyerSpeedWPM); // makes RotaryEncISR.cntValOld different from RotaryEncISR.cntVal  ==> forces display update
            break;
          // -----------------------------
          case 3:
            program_state = S_SET_OUTPUT_POWER;
            RotaryEncPush(&RotaryEnc_OutPowerMiliWatt); // makes RotaryEncISR.cntValOld different from RotaryEncISR.cntVal  ==> forces display update
            break;
          // -----------------------------
          case 4:
            program_state = S_SET_KEYER_TYPE;
            RotaryEncPush(&RotaryEnc_KeyerType); // makes RotaryEncISR.cntValOld different from RotaryEncISR.cntVal  ==> forces display update
            break;
          // -----------------------------
          case 5:
            program_state = S_SET_FREQ_OFFSET;
            RotaryEncPush(&RotaryEnc_OffsetHz); // makes RotaryEncISR.cntValOld different from RotaryEncISR.cntVal  ==> forces display update
            break;
          // -----------------------------
          case 6:
            program_state = S_SET_BUZZER_FREQ;
            RotaryEncPush(&RotaryEnc_BuzzerFreq); // makes RotaryEncISR.cntValOld different from RotaryEncISR.cntVal  ==> forces display update
            break;
          // -----------------------------
          case 7:
            program_state = S_SET_PTT_TIMEOUT;
            RotaryEncPush(&RotaryEnc_PttTimeout); // makes RotaryEncISR.cntValOld different from RotaryEncISR.cntVal  ==> forces display update
            break;
          // -----------------------------          
          case 8:
            program_state  = S_SET_TEXT_GENERIC;
            set_text_state = S_SET_MY_CALL;
            s_general_ascii_buf = s_mycall_ascii_buf.substring(0);
            RotaryEncPush(&RotaryEnc_TextInput_Char_Index);
            RotaryEncISR.cntVal = s_general_ascii_buf[0];
            general_ascii_buf_index = 0;
            break;
          // -----------------------------          
          case 9:
            program_state  = S_SET_TEXT_GENERIC;
            set_text_state = S_SET_M1_TEXT;
            s_general_ascii_buf = s_M1_ascii_buf.substring(0);
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

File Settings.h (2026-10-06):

//
// Keeping original note from example coming with SX12XX library
//
/*******************************************************************************************************
  Programs for Arduino - Copyright of the author Stuart Robinson - 02/03/20

  This program is supplied as is, it is up to the user of the program to decide if the program is
  suitable for the intended purpose and free from errors.
*******************************************************************************************************/

//*******  Setup hardware pin definitions here ! ***************

//These are the pin definitions for one of my own boards, a ESP32 shield base with BBF board shield on
//top. Be sure to change the definitions to match your own setup. Some pins such as DIO2, DIO3, BUZZER
//may not be in used by this sketch so they do not need to be connected and should be included and be 
//set to -1.


// JU: LoRa1281F27 Module from NiceRF
//
// 1 VCC 		- 2.0-5.5v Connected to the positive pole of the power supply
// 2 GND 		- Power ground
// 3 NRESET 	I 0-3.3V Chip reset trigger pin, active low
// 4 BUSY 		O 0-3.3V Status indicator pin (see SX1280/1281 specification for details)
// 5 DIO1 		O 0-3.3V
// 6 DIO2 		O 0-3.3V
// 7 DIO3 		O 0-3.3V
// 8 NSS 		I 0-3.3V Module chip select pin
// 9 SCK 		I 0-3.3V SPI clock input pin
// 10 MOSI 	I 0-3.3V SPI data input pin
// 11 MISO 	O 0-3.3V SPI data output pin
// 12,15.16 	GND - - Connected to the negative pole
// 13 TXEN 	I 0-3.3V
// 14 RXEN 	I 0-3.3V
// 17 			ANT - - Connect with 50 ohm coaxial antenna
// 18 			GND - - Connected to the negative pole

// https://github.com/Xinyuan-LilyGO/TTGO-T-Display/issues/14 :
//Found the answer, the following pin mappings worked for me:
//#define PIN_MISO  27  // GPIO27
//#define PIN_MOSI  26  // GPIO26
//#define PIN_SCK   25  // GIPO25
//#define PIN_CS    33  // GPIO33

// https://www.esp32.com/viewtopic.php?t=13697 :
// you can only use GPIO34 and higher as inputs, not outputs 

//#define Program_Version "v1.0"
//#define Program_Version "v1.1"   // Corrected edge processing from rotary encoder 0x0E instead 0x01)
//#define Program_Version "v1.2"   // 2022-12-22 JU, Rotary encoder direction made configurable via menu
//#define Program_Version "v1.3"     // 2023-02-02 JU, Added support for Iambic-B keying. Based on request of Markus DL6YYM
//#define Program_Version "v1.4"     // 2023-02-06 JU, fixing Iambic-B behaviour, ...
//#define Program_Version "v1.5"     // 2023-02-10 JU, again fixing Iambic-B behaviour, PTT fix, added configurable Messages1 which can be played over HTML form
//#define Program_Version "v1.6"     // 2026-10-05 OK1CDJ, Wi-Fi keep-alive (no modem sleep, reconnect), OTA update via web
#define Program_Version "v1.7"     // 2026-10-06 OK1CDJ, Feld Hell beacon set from web, web layout for mobile


#define NSS 5                                  //select pin on LoRa device
#define SCK 18                                  //SCK on SPI3
#define MISO 19                                 //MISO on SPI3 
#define MOSI 23                                 //MOSI on SPI3 

#define NRESET 32                               //reset pin on LoRa device
#define RFBUSY 16                               //busy line

#define LED1 15                                 //on board LED, high for on
#define DIO1 13                                 //DIO1 pin on LoRa device, used for RX and TX done 
#define DIO2 -1                                 //DIO2 pin on LoRa device, normally not used so set to -1 
#define DIO3 -1                                 //DIO3 pin on LoRa device, normally not used so set to -1
#define RX_EN 4                                //pin for RX enable, used on some SX128X devices, set to -1 if not used
#define TX_EN 2                                 //pin for TX enable, used on some SX128X devices, set to -1 if not used
#define BUZZER 33                               //pin for buzzer, set to -1 if not used 
#define VCCPOWER 17    //JU-not needed by module          //pin controls power to external devices
#define LORA_DEVICE DEVICE_SX1281               //we need to define the device we are using
#define TCXO_EN 14
#define PTT_OUT 12

#define LOOP_PTT_MULT_VALUE 1000  // Value by which PttTimeout counter is multiplied - we need this since mail loop is running very fast
                                  // But be careful not to exceed max value of int32 variable of PttTimeout counter

// Pin definitions

#define ROTARY_ENC_A     26    // Rotary encoder contact A 
#define ROTARY_ENC_B     27    // Rotary encoder contact B 

#define ROTARY_ENC_PUSH  25    // Rotary encoder pushbutton
//
#define KEYER_DOT       34    // Morse keyer DOT          NOTE: GPIOs 34 to 39 INPUTs only / No internal pullup / No int. pulldown
#define KEYER_DASH      35    // Morse keyer DASH

//

#define NGLYPHS         (sizeof(glyphtab)/sizeof(glyphtab[0]))

//*******  Setup LoRa Parameters Here ! ***************
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

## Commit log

2021-09-04 Update SX1281_QO100_TX.ino
    TX is now working, user can now set TX power from 50mW to 450mW, parameters such as Callsign, WiFi SSID, Password can be configured and are stored in NVM
2021-09-09 Update SX1281_QO100_TX.ino
    JU:
    - Buzzer-frequency made configurable and stored in NV memory
    - added timeout for display items other than main screen
    - minor changes in graphic layout
    [SX1281_QO100_TX.ino]
2021-09-16 Upadate of web interface
    added frequency and power control
2021-09-24 Added LED to PIN 15
2021-11-08 Update SX1281_QO100_TX.ino
    - Morse message concept changed to use Queues, should be safer
    - UDP: now can receive some invalid Morse characters; these are encoded by character value >= 128
    - UDP: remote part can adjust Frequency, Power and WPM by special UDP packet
2021-11-08 Update index.html
    - added sending dots button
2021-12-08 Update SX1281_QO100_TX.ino
    Changes OM2JU:
    - added decoding of optional 2nd UPD packet with repeated information (if first UPD is missed the second will be used = improves reliability over WiFi)
    - code cleanup around interrupt routine + general cleanup
    [SX1281_QO100_TX.ino]
2022-07-26 Update SX1281_QO100_TX.ino
    JU 2022-07-26:
    - Updated edge detection in Rotary encoder ISR onTimer() so that it now works reliably
    - WPM setting via UDP - resulting WPM is made a bit slower so that there are less "pauses" when keying via UDP
    - see Calc_WPM_dot_delay_a_bit_slower()
2022-07-26 Update Settings.h
    v1.1 - corrected edge processing from rotary encoder
    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
    [Settings.h]
2025-05-19 Eagle and Gerbers
    [tx-qo100-botcase.brd, tx-qo100-topcase.brd, tx-qo100-v3.brd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]
2026-10-03 Initial commit: cwdaemon Tk client with Cloudlog logging
    - JSON config (config.example.json) for UDP target, station, macros,
    Cloudlog and ADIF settings; CLI args override Cloudlog credentials
    - Fix Cloudlog check (accept any 2xx), RST sent/received in ADIF,
    logger shadowing, GUI startup outside main
    - F1-F5 macro keys, Esc/STOP aborts transmission, status line
    - README, requirements.txt, .gitignore (config.json holds API key)
    - PureBasic port (CWclient.pb) and test.py kept as-is
2026-10-03 Add keyer frequency control, power, tune and firmware notes
    - Read TX frequency from the keyer web UI, show TX/RX in the app and
    log it with each QSO (FREQ_RX = TX + 8089.5 MHz)
    - Tuning with selectable step (keyer step, 1/10/100 kHz), mouse wheel,
    PgUp/PgDn and direct MHz entry; frequency memories in memories.json
    - TCXO correction via keyer_web.correction_hz
    - Power selection and TUNE (fixed 3 s carrier in firmware); STOP/Esc
    also sends Break to the keyer
    - Keyer HTTP calls run in a background thread so the GUI never blocks
    - firmware/: analysis of SX1281_QO100_TX Wi-Fi drops with Deco, an
    untested keep-alive patch and a ping monitor script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
2026-10-03 Replace TUNE with DOTS, add PlatformIO build for keyer firmware
    - DOTS (F6) sends the keyer's dot series for tuning onto the
    transponder; STOP/Esc sends Break which clears the CW queue.
    TUNE removed (fixed 3 s blocking carrier in firmware, not used)
    - firmware/platformio.ini: builds SX1281_QO100_TX with Arduino core
    2.0.17 (espressif32@6.9.0); upstream v1.5 and v1.1 build, also with
    the Wi-Fi keep-alive patch
    - firmware/README.md: local ~/Arduino copy = upstream v1.1, changes
    up to v1.5, build and flash steps
    Claude-Session: https://claude.ai/code/session_016D7AMLyh9edUJhp2Q2hEko
2026-10-05 Add keyer OTA patch, test keyer firmware on spare board
    - firmware/ota.patch: POST /ota (firmware or SPIFFS), working /update page
    - platformio.ini: [env:ota] uploads over Wi-Fi via curl
    - keyer_monitor.sh takes the host as an argument
    - README: OTA usage, USB flashing notes (BOOT button, 115200 for SPIFFS)
2026-10-05 Wi-Fi: disable modem sleep, reconnect when the station drops
    Some access points (TP-Link Deco mesh) drop ESP32 stations in modem
    sleep - the keyer fell off Wi-Fi a few minutes after connecting, even
    without transmitting, and never came back.
    - WiFi.setSleep(false) after connecting
    - WiFi.setAutoReconnect(true), WiFi.persistent(false)
    - WiFiKeepAlive() in loop(): WiFi.begin() again every 10 s while
    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
2026-10-05 OTA update over Wi-Fi: /ota endpoint, working /update page
    POST /ota?apikey=KEY[&target=fs] with a multipart file writes the
    firmware (other OTA app slot) or, for spiffs.bin / target=fs, the
    SPIFFS web files. TX is stopped before writing; the keyer restarts
    1 s after a successful upload. Settings in NVS are kept.
    The /update page (form only until now) uploads the chosen file with
    a progress bar. It avoids a literal percent sign because the page
    goes through the template processor.
    [SX1281_QO100_TX.ino]
2026-10-05 Add PlatformIO build with OTA upload environment
    env:esp32dev builds with Arduino core 2.0.17 (espressif32@6.9.0) and
    the ESP32Async forks of ESPAsyncWebServer / AsyncTCP. env:ota uploads
    firmware.bin or spiffs.bin to /ota with curl.
2026-10-05 Add Pythonista (iPad) client, move shared logic to cwcore.py
    - cwcore.py: config, cwdaemon, keyer web client, ADIF, Cloudlog and a
    Session class with the tuning/memory/power logic; GUIs plug in via
    post/call_later callbacks
    - pyCWdclient.py: Tk frontend over Session (unchanged UI); Cloudlog
    upload no longer blocks the window, GO with the keyer offline no
    longer fails
    - pyCWdclient_ios.py: Pythonista touch UI, hardware keyboard shortcuts;
    Session runs in its own loop thread (on_main_thread/ui.delay crashed
    Pythonista when tuning), faulthandler writes crash.log
    - ignore crash.log and firmware/*.bin (flash backups)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
2026-10-06 v1.7: Feld Hell beacon set from web, web layout for mobile
    - Feld Hell runs in its own task with deadline timing (245 px/s), keys only on
    changes and stops within one column; loop(), Wi-Fi and UDP keep running
    - Beacon text (%CALL% = MyCall), repetitions and pause stored in preferences,
    set on the web page; start/stop from web, menu, /hell endpoint, Break or push button
    - Font: added - = + : ; , ' @, unknown characters are sent as space
    - index.html: wraps on narrow screens, removed date mask from the text field
2026-10-06 Feld Hell TX mode: CW/Hell switch, Hell text sent via keyer /hell, ADIF MODE=HELL
2026-10-06 pyCWdclient: CW / Hell mode labels, mode switch next to Log QSO, Hell RX screenshot
2026-10-06 README: current web UI screenshot (v1.7, memories, Dots, Feld Hell beacon)

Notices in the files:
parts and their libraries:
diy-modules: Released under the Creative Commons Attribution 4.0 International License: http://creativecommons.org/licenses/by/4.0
